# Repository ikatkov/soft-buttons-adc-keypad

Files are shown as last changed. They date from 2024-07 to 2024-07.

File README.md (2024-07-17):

# ADC based keypad

This is a 3-wires ADC based 3x3 keypad. Only 3 pins Vcc-GND-ADC.

Ideal to be used with salvaged silicon buttons from remote controls.
There is a momentary button under silicon cap.

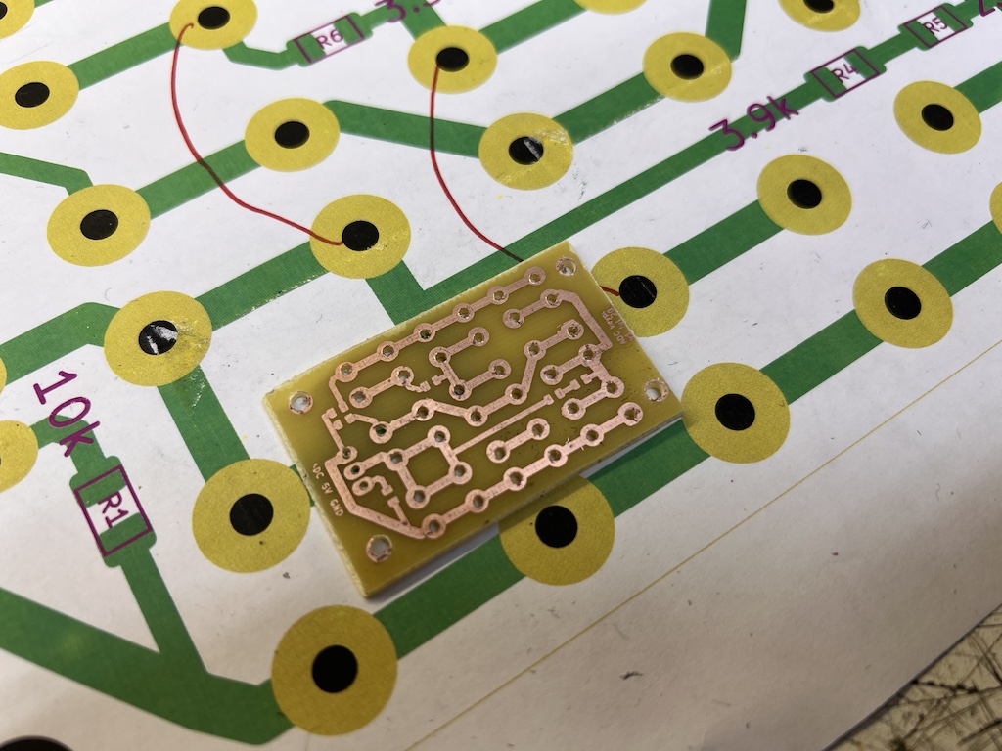
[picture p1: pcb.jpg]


# Code

```

enum KEYPAD_BUTTONS
{
    BTN_NOT_PRESSED, // 0
    BTN_TOP_LEFT,    // 1
    BTN_UP,          // 2
    BTN_TOP_RIGHT,   // 3
    BTN_LEFT,        // 4
    BTN_CENTER,      // 5
    BTN_RIGHT,       // 6
    BTN_BACK,        // 7
    BTN_DOWN,        // 8
    BTN_MENU         // 9
};
const char *buttonsNames[] = {"NOT PRESSED", "BTN_TOP_LEFT", "BTN_UP", "BTN_TOP_RIGHT", "BTN_LEFT", "BTN_CENTER", "BTN_RIGHT", "BTN_BACK", "BTN_DOWN", "BTN_MENU"};
KEYPAD_BUTTONS prev_button_pressed = BTN_NOT_PRESSED;

byte read_buttons()
{
    int voltage = analogRead(A0);
    KEYPAD_BUTTONS result = BTN_NOT_PRESSED;
    KEYPAD_BUTTONS new_button_pressed = BTN_NOT_PRESSED;
    if (voltage >= 540 && voltage <= 590) // 558
        new_button_pressed = BTN_MENU;
    else if (voltage >= 650 && voltage < 670) // 655
        new_button_pressed = BTN_DOWN;
    else if (voltage >= 800 && voltage <= 845) // 825
        new_button_pressed = BTN_BACK;
    else if (voltage >= 580 && voltage <= 615) // 596
        new_button_pressed = BTN_RIGHT;
    else if (voltage >= 700 && voltage <= 725) // 708
        new_button_pressed = BTN_CENTER;
    else if (voltage >= 890 && voltage <= 940) // 912
        new_button_pressed = BTN_LEFT;
    else if (voltage >= 620 && voltage <= 640) // 631
        new_button_pressed = BTN_TOP_RIGHT;
    else if (voltage >= 740 && voltage <= 775) // 759
        new_button_pressed = BTN_UP;
    else if (voltage >= 980 && voltage <= 1023) // 1000
        new_button_pressed = BTN_TOP_LEFT;

    if (new_button_pressed == BTN_NOT_PRESSED && prev_button_pressed != BTN_NOT_PRESSED)
    {
        // button was released
        result = prev_button_pressed;
        prev_button_pressed = BTN_NOT_PRESSED;
    }
    else if (new_button_pressed != BTN_NOT_PRESSED && prev_button_pressed == BTN_NOT_PRESSED)
    {
        // button was pressed
        prev_button_pressed = new_button_pressed;
    }
    return result;
}

...

void loop()
{
    byte command = read_buttons();
    if (command != BTN_NOT_PRESSED)
    {
    	...
	}
}

```

# Notes

Performance seems OK. 

One disadvantage is that you need to alter source code when real ADC values are captured.
Some buttons yeld ADC valus that are very close to each other. I'm concern about long-term reliability.
You need to poll the state periodically, but you don't need to debounce.

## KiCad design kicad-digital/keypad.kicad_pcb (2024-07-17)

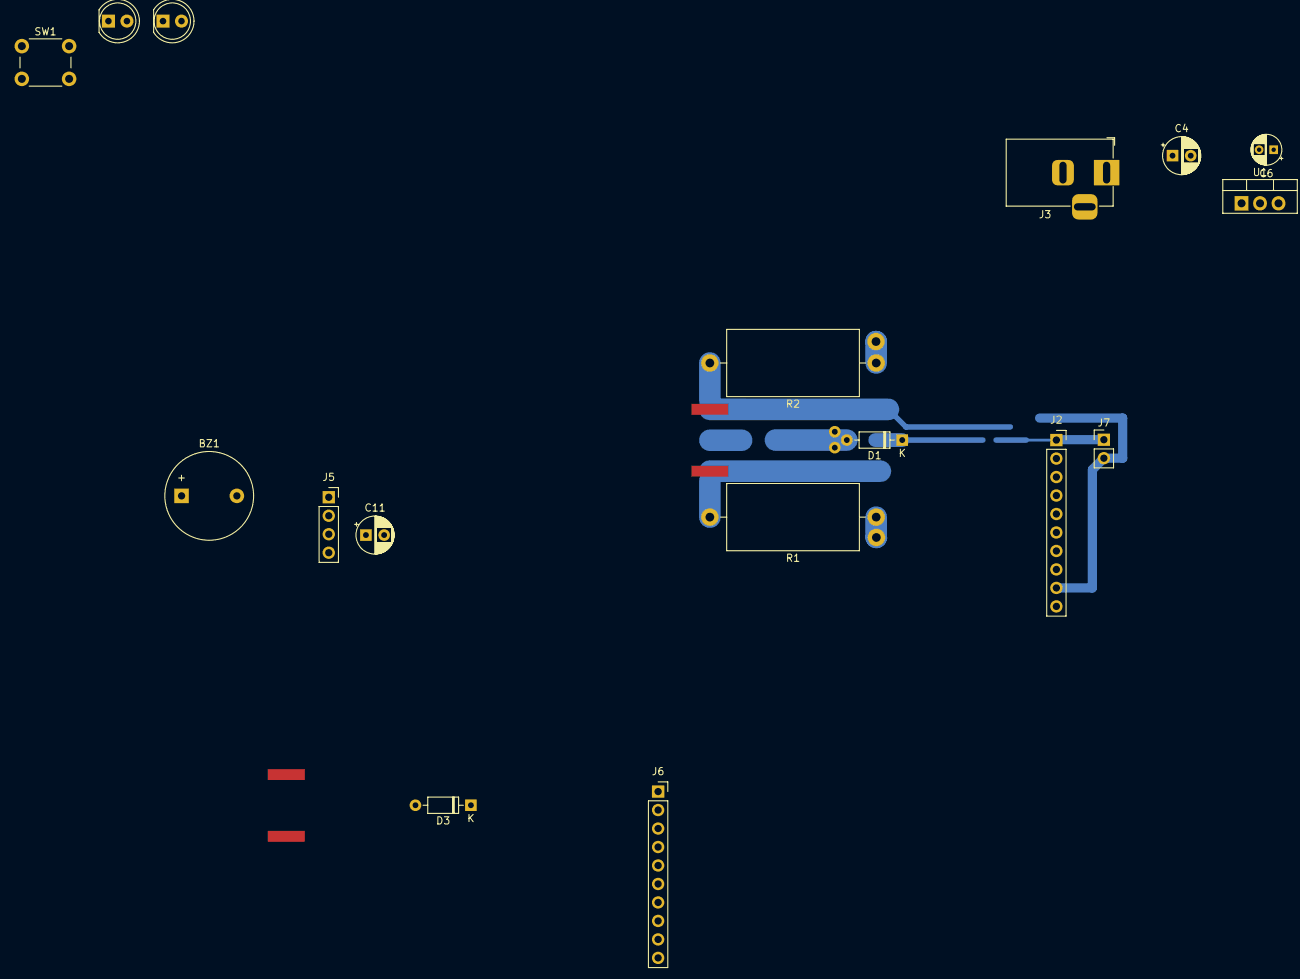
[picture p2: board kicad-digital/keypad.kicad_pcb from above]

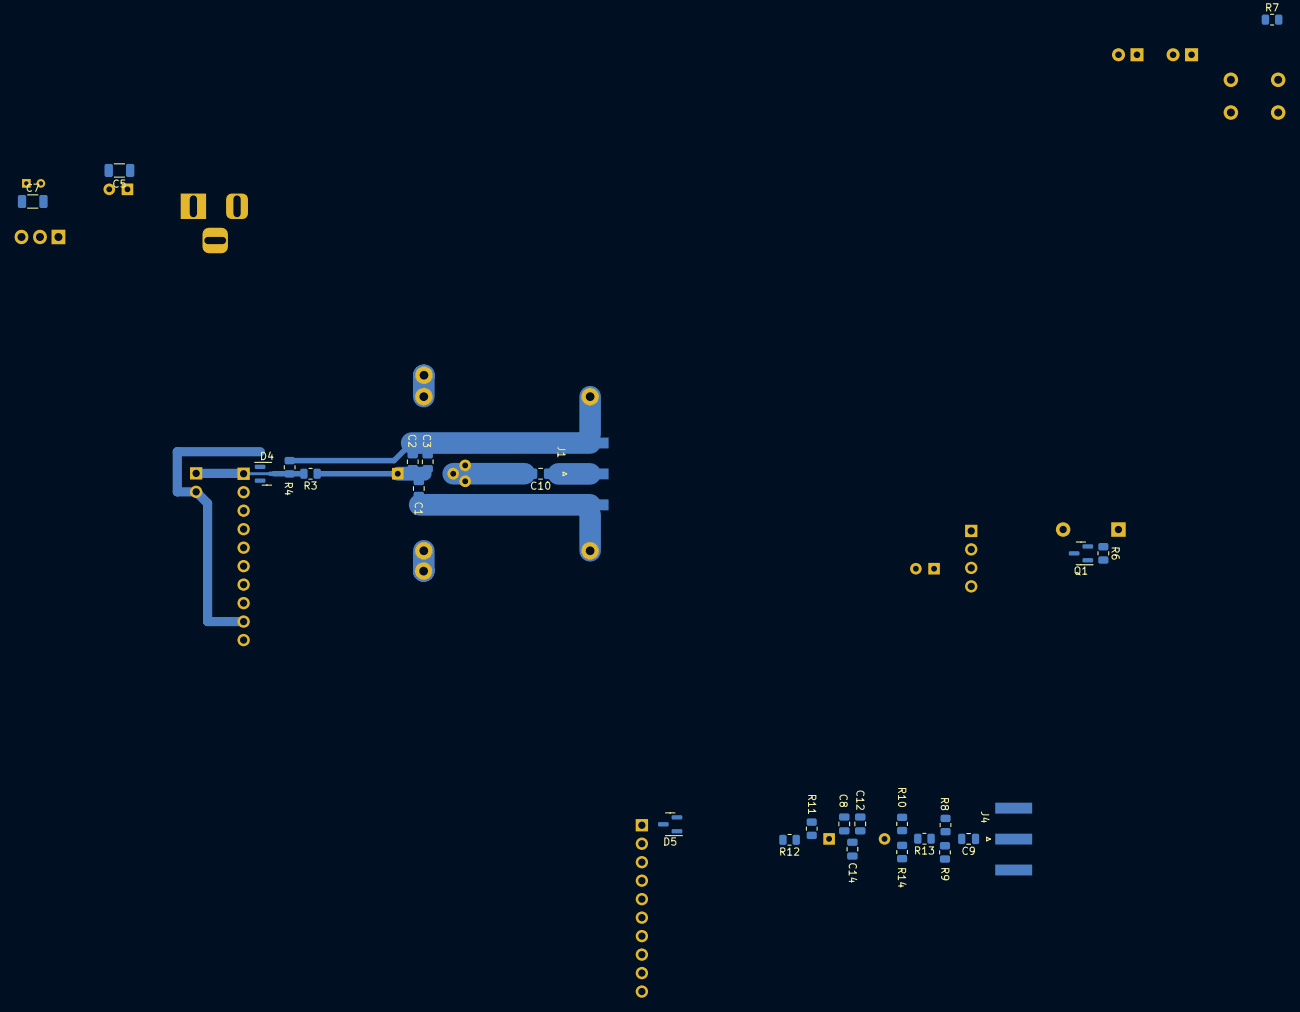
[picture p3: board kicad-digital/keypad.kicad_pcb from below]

Board: 4 copper layers, 43 parts (26 on the bottom side), 19 nets.

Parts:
BZ1: Buzzer; Buzzer_12x9.5RM7.6
C1, C14: 3.3n; C_0805_2012Metric
C2, C12: 100p; C_0805_2012Metric
C3, C8: 10p; C_0805_2012Metric
C4, C11: 100u; CP_Radial_D5.0mm_P2.50mm
C5, C7: 100n; C_1206_3216Metric
C6: 22u; CP_Radial_D4.0mm_P2.00mm
C9, C10: 15n; C_0805_2012Metric
D1, D3: 1N5711; D_DO-35_SOD27_P7.62mm_Horizontal
D2: HI_Port; LED_D5.0mm
D4, D5: BAT54S; SOT-23
D6: LO_Port; LED_D5.0mm
J1, J4: SMA; SMA_Amphenol_132289_EdgeMount
J2, J6: ADS1115; PinSocket_1x10_P2.54mm_Vertical
J3: Barrel_Jack; BarrelJack_Horizontal
J5: Display; PinSocket_1x04_P2.54mm_Vertical
J7: TestPoint; PinHeader_1x02_P2.54mm_Vertical
Q1: 2N3904; SOT-23
R1, R2: 100; R_Axial_DIN0918_L18.0mm_D9.0mm_P22.86mm_Horizontal
R3: 180k; R_0805_2012Metric
R4: 36k; R_0805_2012Metric
R6, R12: 1k; R_0805_2012Metric
R7: 3k; R_0805_2012Metric
R8: 620; R_0805_2012Metric
R9: 560; R_0805_2012Metric
R10: 91; R_0805_2012Metric
R11: 270k; R_0805_2012Metric
R13: 18; R_0805_2012Metric
R14: 82; R_0805_2012Metric
SW1: HI/LO port; SW_PUSH_6mm
U1: L7805; TO-220-3_Vertical

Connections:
+12V: C4.1, C5.1, J3.1, U1.1 (IN)
A3: D4.3 (COM), J2.1, J7.1, R3.2, R4.1
GND: C4.2, C5.2, C6.2, C7.2, D2.1 (K), D4.1 (A), D5.1 (A), J2.9, J3.2, J5.1, J7.2, Q1.2 (E), SW1.2, U1.2 (GND)
GNDA: C1.2, C2.2, C3.2, C8.1, J1.2 (Ext), R1.2, R2.2, R4.2, R9.1, R10.1
unnamed: BZ1.2 (+), Q1.3 (C)
unnamed: C9.2, R8.1, R9.2, R13.1
unnamed: C10.2, D1.2 (A), R1.1, R2.1
unnamed: C1.1, C2.1, C3.1, D1.1 (K), R3.1
unnamed: D2.2 (A), D6.1 (K), R7.2
unnamed: D3.2 (A), R10.2, R13.2, R14.1
unnamed: C8.2, C12.1, C14.1, D3.1 (K), R11.1, R12.1
unnamed: D5.3 (COM), R12.2
unnamed: C10.1, J1.1 (In)
unnamed: C12.2, C14.2, J4.2 (Ext), R8.2, R11.2, R14.2
unnamed: C9.1, J4.1 (In)
unnamed: Q1.1 (B), R6.2
SDA: J2.7, J5.3
SLC: J2.8, J5.4
VCC: BZ1.1 (-), C6.1, C7.1, D4.2 (K), D5.2 (K), D6.2 (A), J2.10, J5.2, U1.3 (OUT)

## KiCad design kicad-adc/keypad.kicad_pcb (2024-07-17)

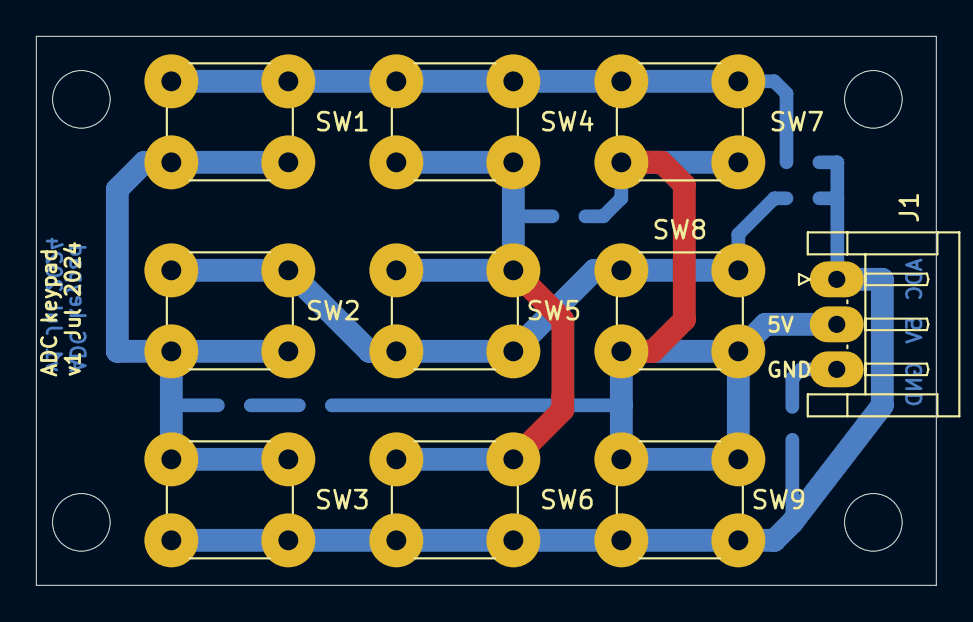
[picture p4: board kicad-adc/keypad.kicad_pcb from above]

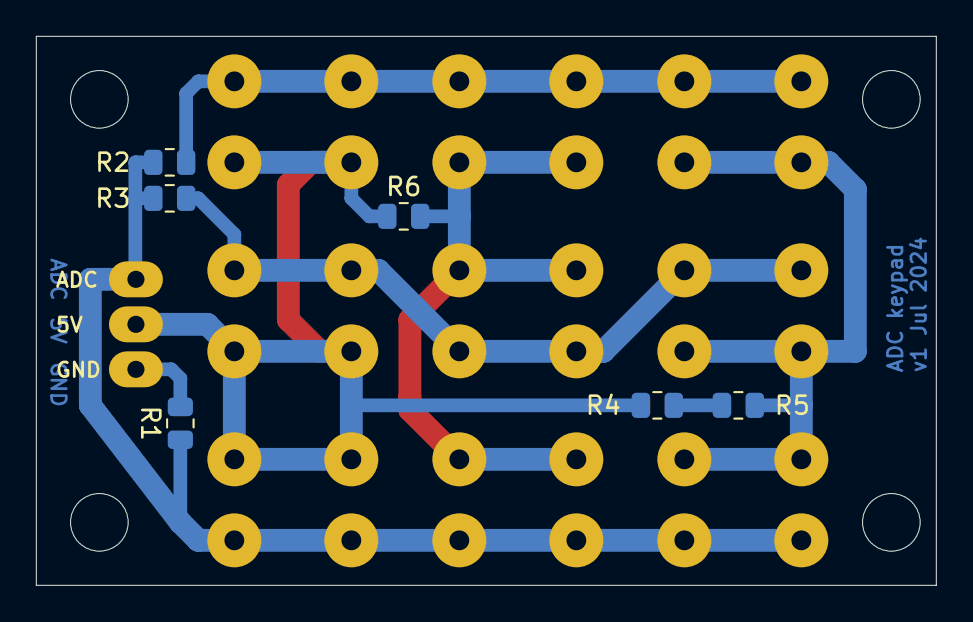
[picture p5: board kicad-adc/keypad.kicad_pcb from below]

Board: 4 copper layers, 50.0 x 30.5 mm, 20 parts (6 on the bottom side), 8 nets.

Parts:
H1, H2, H3, H4: MountingHole; MountingHole_3.2mm_M3
J1: Conn; JST_EH_S3B-EH_1x03_P2.50mm_Horizontal
R1: 10k; R_0805_2012Metric
R2, R5: 2.2k; R_0805_2012Metric
R3: 1k; R_0805_2012Metric
R4: 3.9k; R_0805_2012Metric
R6: 3.3k; R_0805_2012Metric
SW1, SW2, SW3, SW4, SW5, SW6, SW7, SW8, SW9: B1; SW_PUSH_6mm

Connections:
+5V: J1.2, R4.1, R6.1, SW7.2, SW8.2, SW9.2
ADC: J1.1, R1.1, R2.2, R3.2, SW3.1, SW6.1, SW9.1
GND: J1.3, R1.2
unnamed: R2.1, SW1.1, SW4.1, SW7.1
unnamed: R3.1, SW2.1, SW5.1, SW8.1
unnamed: R4.2, R5.1
unnamed: R5.2, SW1.2, SW2.2, SW3.2
unnamed: R6.2, SW4.2, SW5.2, SW6.2
